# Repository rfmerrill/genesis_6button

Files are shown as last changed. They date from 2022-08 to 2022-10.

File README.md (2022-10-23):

# genesis_6button
Simple PCB + ATTiny404 code for a 6-button mega drive controller.

This is a KiCad project for a board and accompanying ATTiny404 code to implement a replacement for the custom chip in the 6-button mega drive/genesis controller.

**Note: the `main` HEAD is not necessarily tested! Tested revisions of the board+firmware will be tagged**

Latest tested fab here: https://oshpark.com/shared_projects/aK2wBkfg

Currently there is a 14-pin dual row header used for the buttons because I was unaware of the brook 20 pin header at the time. I might add that pinout to future boards.

```
     C  1 | 2  Z
     B  3 | 4  Y
     A  5 | 6  X
  LEFT  7 | 8 GND
 RIGHT  9 | 10 GND
  DOWN 11 | 12 MODE
    UP 13 | 14 START
```

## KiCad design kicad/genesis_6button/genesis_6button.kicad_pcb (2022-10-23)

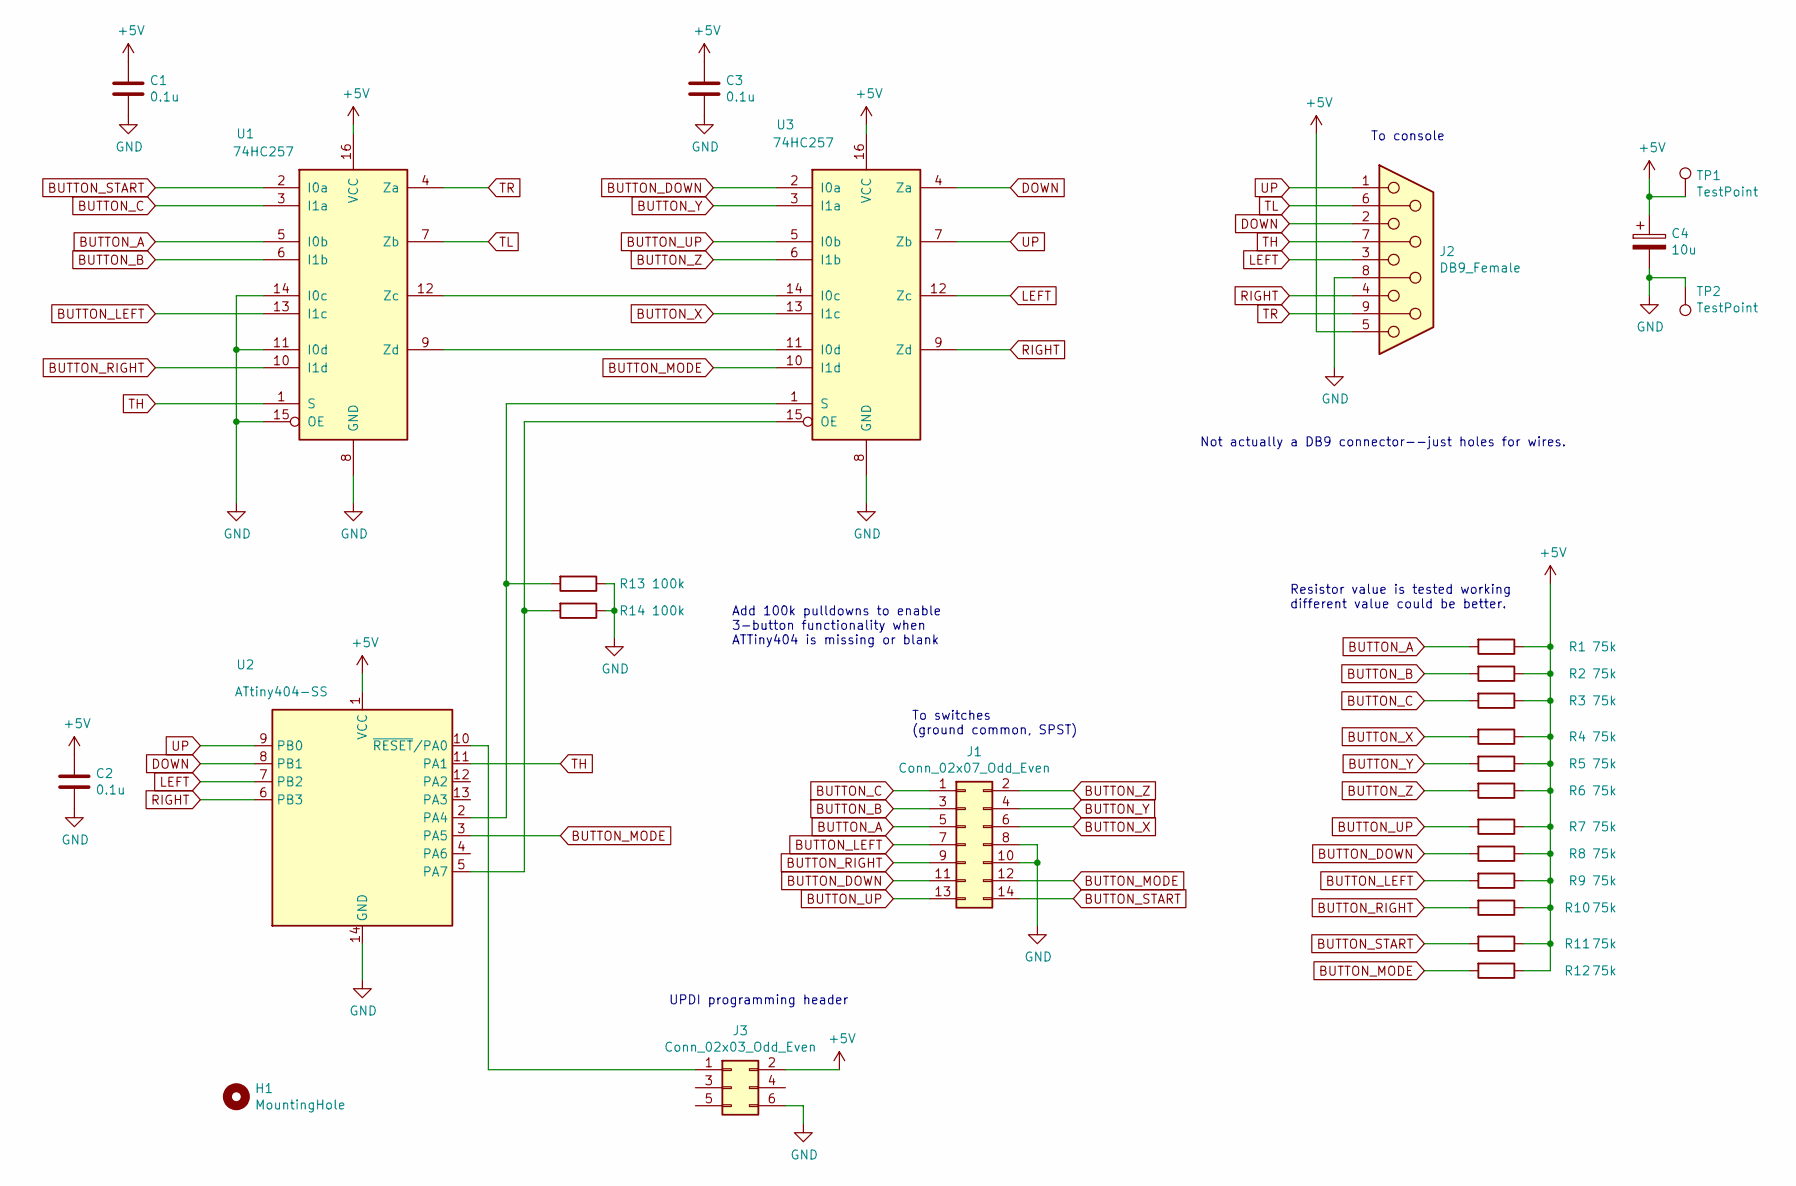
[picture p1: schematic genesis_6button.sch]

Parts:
C1, C2, C3: 0.1u; C_1206_3216Metric
C4: 10u; CP_Radial_D8.0mm_P5.00mm
H1: MountingHole; MountingHole_5.3mm_M5
J1: Conn_02x07_Odd_Even; IDC-Header_2x07_P2.54mm_Vertical
J2: DB9_Female; PinHeader_1x09_P2.54mm_Vertical
J3: Conn_02x03_Odd_Even; IDC-Header_2x03_P2.54mm_Vertical
R1, R2, R3, R4, R5, R6, R7, R8, R9, R10, R11, R12: 75k; R_0805_2012Metric
R13, R14: 100k; R_0805_2012Metric
TP1, TP2: TestPoint; TestPoint_Loop_D3.50mm_Drill0.9mm_Beaded
U1, U3: 74HC257; SOIC-16_3.9x9.9mm_P1.27mm
U2: ATtiny404-SS; SOIC-14_3.9x8.7mm_P1.27mm

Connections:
+5V: C1.1, C2.1, C3.1, C4.1, J2.5, J3.2, R1.1, R2.1, R3.1, R4.1, R5.1, R6.1, R7.1, R8.1, R9.1, R10.1, R11.1, R12.1, TP1.1, U1.16 (VCC), U2.1 (VCC), U3.16 (VCC)
BUTTON_A: J1.5, R1.2, U1.5 (I0b)
BUTTON_B: J1.3, R2.2, U1.6 (I1b)
BUTTON_C: J1.1, R3.2, U1.3 (I1a)
BUTTON_DOWN: J1.11, R8.2, U3.2 (I0a)
BUTTON_LEFT: J1.7, R9.2, U1.13 (I1c)
BUTTON_MODE: J1.12, R12.2, U2.3 (PA5), U3.10 (I1d)
BUTTON_RIGHT: J1.9, R10.2, U1.10 (I1d)
BUTTON_START: J1.14, R11.2, U1.2 (I0a)
BUTTON_UP: J1.13, R7.2, U3.5 (I0b)
BUTTON_X: J1.6, R4.2, U3.13 (I1c)
BUTTON_Y: J1.4, R5.2, U3.3 (I1a)
BUTTON_Z: J1.2, R6.2, U3.6 (I1b)
DOWN: J2.2, U2.8 (PB1), U3.4 (Za)
GND: C1.2, C2.2, C3.2, C4.2, J1.8, J1.10, J2.8, J3.6, R13.1, R14.1, TP2.1, U1.8 (GND), U1.11 (I0d), U1.14 (I0c), U1.15 (OE), U2.14 (GND), U3.8 (GND)
LEFT: J2.3, U2.7 (PB2), U3.12 (Zc)
unnamed: J3.1, U2.10 (~RESET~/PA0)
unnamed: R13.2, U2.2 (PA4), U3.1 (S)
unnamed: R14.2, U2.5 (PA7), U3.15 (OE)
unnamed: U1.9 (Zd), U3.11 (I0d)
unnamed: U1.12 (Zc), U3.14 (I0c)
RIGHT: J2.4, U2.6 (PB3), U3.9 (Zd)
TH: J2.7, U1.1 (S), U2.11 (PA1)
TL: J2.6, U1.7 (Zb)
TR: J2.9, U1.4 (Za)
UP: J2.1, U2.9 (PB0), U3.7 (Zb)

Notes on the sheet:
Not actually a DB9 connector--just holes for wires.
UPDI programming header
Resistor value is tested working different value could be better.
Add 100k pulldowns to enable 3-button functionality when ATTiny404 is missing or blank
To console
To switches (ground common, SPST)

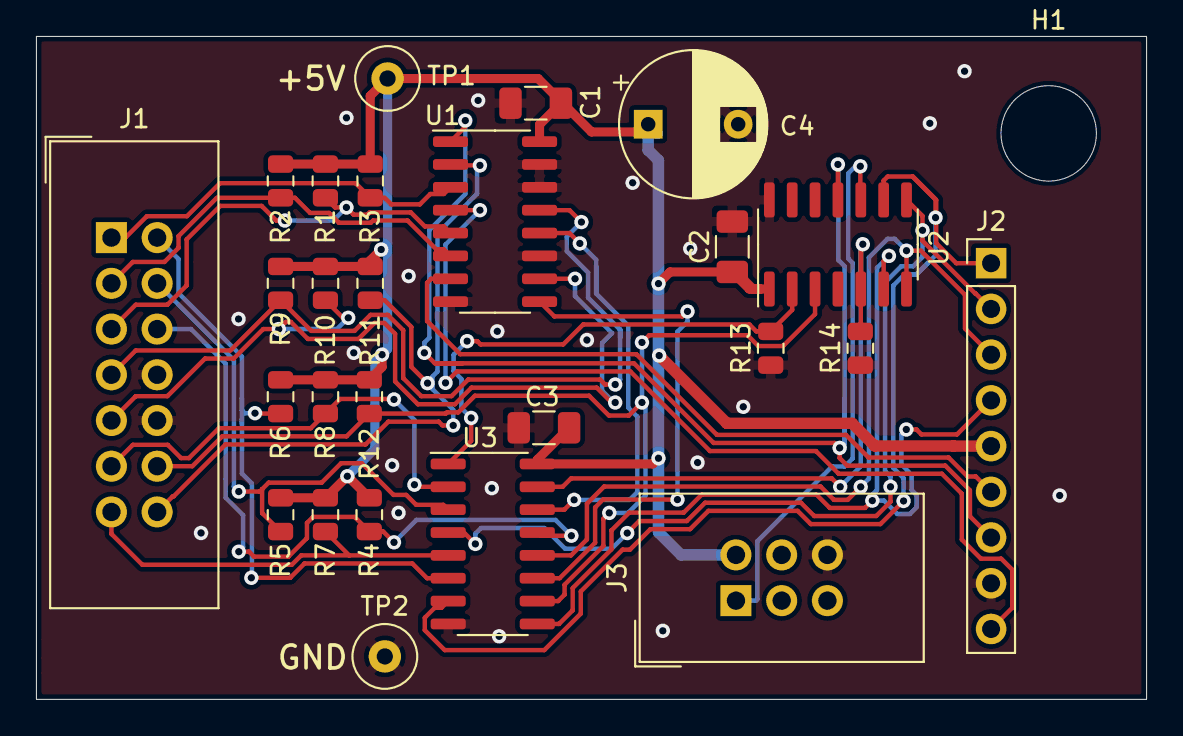
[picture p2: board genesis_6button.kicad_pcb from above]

Board: 2 copper layers, 61.7 x 36.8 mm, 27 parts (0 on the bottom side), 26 nets.

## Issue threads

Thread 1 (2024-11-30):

Hex file of Attiny404

hualazimo7, 2024-11-30:
Can you provide the firmware of attiny404?

rfmerrill, 2024-12-03:
It's been so long since I touched this project that I no longer am sure which revision I should build to give you a hex file, plus I have a new computer and don't have the compiler installed anymore. I might be able to get it for you in a while but I would want to be able to re-test it before I tell anyone to use it, which would mean finding one of the boards, hooking it up etc etc.

It shouldn't be too hard for you to build yourself--it's a really simple project, and Atmel Studio/Microchip Studio is free and not too hard to install.

Closed 2024-12-09.

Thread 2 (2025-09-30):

BOM, cable wiring, improved silkscreen

danboid, 2025-09-30:
I'm interested in building one of these boards but it needs a bit more documentation.

Could you please add a BOM to the repo? It seems there is a mostly complete BOM here:

https://oshpark.com/shared_projects/aK2wBkfg

but it is missing designators for the parts - its mainly U1, U2 and U3 and J3 that I'm unsure of.

I would also need a pinout diagram showing how to wire J2 up to a cable.

It would be good to see the silkscreen improved to show the button wiring on the PCB.

Thanks

rfmerrill, 2025-09-30:
All of the information you need is in the KiCAD project, but I didn't include a schematic print in the repo which is actually a pet peeve of mine when other people do it. Unfortunately it's been so long that I don't think I even have KiCAD installed anymore.

> but it is missing designators for the parts - its mainly U1, U2 and U3 and J3 that I'm unsure of.

It should be obvious which footprint is the microcontroller and which are the two multiplexers because they have different pin counts. I believe U2 is the microcontroller.

J3 is a standard 2x3 IDC header, which I _think_ will mate with either the USBtinyISP or the Atmel ICE's AVR adapter pigtail. If you just search for "2x3 IDC socket" pretty much any of them will work as long as you get one with the common 0.1" pin pitch.

> I would also need a pinout diagram showing how to wire J2 up to a cable.

Ah I feel bad that I didn't include this because I don't even remember! I want to believe that I was a good boy and used the same pin numbering as the joystick connector itself, but I cannot guarantee that I did, unfortunately.

> It would be good to see the silkscreen improved to show the button wiring on the PCB and adding a photo of a populated, wired board to the README.

Agree, and these seem like easy tasks for someone to do :)

rfmerrill, 2025-09-30:
OK, I have been able to confirm that I _was_ in fact a good boy and J2's pin numbering matches the joystick plug. Note: that pinout diagram you posted reflects the _socket_--the plug is mirrored from that. Also those pinout descriptions are for the actual atari consoles, but we only care about the pin numbers in this case.

Here is a photo of one of the boards I assembled that I was able to dig up:

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

Please **ignore the wire colors** as while Sega may have been consistent, third parties definitely were not.

There are a handful of minor mods here--points to clip to for supply voltage, an extra capacitor (don't remember why, probably not needed) and a jumper wire that allows for supporting 3-button mode (hold down MODE on powerup).

You'll also notice I just used 2-row pin headers instead of IDC. This is also fine it just means you lose the keying and have to pay attention to pin 1.

> Would you recommend that we use the gerbers from the latest commit or the tested version?

Ah, there are not actually any gerbers here... I don't remember what changed from the tested version to the latest commit. Tested version is probably safer I assume.

rfmerrill, 2025-09-30:
And no, that's not hot glue, it's RapidFix UV resin. I don't own a hot glue gun.

danboid, 2025-09-30:
Final question today / tonight is have you ever heard of the open source 8 bit Uzebox games console before I started bombarding you? Its the fastest, cheapest, most open and easiest to build 8 bit console platform, if any of that appeals to you?

https://uzebox.org/

rfmerrill, 2025-10-01:
maybe someday, my time is mostly taken up with work and guitar practice these days. I'm sure I'll get back into gaming sometime!

danboid, 2025-10-02:
Guitar practice is definitely a better use of your time than playing games IMO. I find trying to write games more fun than playing them.

I support the Uzebox because I think we need a fully  open retro platform and its a great project for people learning electronics to get started with. Same goes for the Spectrum Next. They compliment each other well.

danboid, 2025-10-02:
I'm hoping to make a start on building this soon. I've still not even tried building the code yet.

rfmerrill, 2025-10-03:
I don't know if the `main` version of the kicad project even passes DRC or works at all, tbh, but godspeed if you want to try it out.

If you're going to credit me, give my github URL I guess?

danboid, 2025-10-03:
I have got the attiny code to build under Linux using `avr-gcc`. I'm pretty sure you need at least `avr-gcc` v8 or later to build for the attiny404.

I used these commands which we can put into a build script when I update (my fork of) the repo:

```
avr-gcc -mmcu=attiny404 -Os -Wall -Wextra main.c -o main.elf
avr-objcopy -O ihex -R .eeprom main.elf main.hex
```

rfmerrill, 2025-10-03:
@danboid thanks so much! The one thing I'm wondering about is if there were fuse settings you might need in addition to the code. I think I would have put them in the comments if so? I don't think the 404 is one where you have to mess with fuses as much. My memory is so bad though

rfmerrill, 2025-10-03:
> I found it interesting that the latest rev has one mount hole in the top right corner.

Yeah I just wanted a hole I could slip a cable tie into so that the joystick cable isn't hanging by its solder joints. I'm not a mechanical engineer as you can tell.

danboid, 2025-10-04:
According to KiCAD v9's DRC, there was one thermal relief error with the last v1 revision of the PCB. I seem to have fixed that by slightly moving U3. I have most of the information I suggested get added to the silkscreen and I've added 4x M2 mount holes.

I think I'm just about done now apart from maybe rounding the edges of the board off. Could you check I've got the button labels correct please?

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

https://github.com/danboid/genesis_6button

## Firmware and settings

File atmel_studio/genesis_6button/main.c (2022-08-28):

/*
 * genesis_6button.c
 *
 * Created: 8/24/2022 6:51:32 PM
 * Author : rfm
 */

#include <avr/interrupt.h>
#include <avr/io.h>
#include <stdbool.h>

#define F_CPU_HZ 10000000
#define F_PER_HZ 10000000

#define TIMEOUT_SEC 0.002  // 2 ms
#define TIMEOUT_PER_CLKS (F_PER_HZ * TIMEOUT_SEC)

static volatile bool timeout = false;

static inline void pins_3button(void)
{
    cli();
    PORTB_DIR = 0;          // PBx all set to input
    VPORTA_OUT &= ~_BV(4);  // Select 0
    VPORTA_OUT &= ~_BV(7);  // Output enable
    PORTB_OUT = 0x00;       // PB0-3 low pre-load
    sei();
}

static inline void pins_low(void)
{
    cli();
    VPORTA_OUT |= _BV(7);  // Output disable
    PORTB_DIR = 0x0F;      // PB0-3 output
    VPORTA_OUT |= _BV(4);  // Select 1 (pre-load)
    sei();
}

static inline void pins_xyz(void)
{
    cli();
    PORTB_DIR = 0;          // PBx all set to input
    VPORTA_OUT &= ~_BV(7);  // Output enable
    PORTB_OUT = 0x0F;       // PB0-3 drive high pre-load
    sei();
}

static inline void pins_high(void)
{
    cli();
    VPORTA_OUT |= _BV(7);   // Output disable
    PORTB_DIR = 0x0F;       // PB0-3 output
    VPORTA_OUT &= ~_BV(4);  // Select 0 (pre-load)
    sei();
}

ISR(TCA0_CMP0_vect)
{
    TCA0_SINGLE_INTFLAGS = TCA_SINGLE_CMP0_bm;
    TCA0_SINGLE_CTRLA = 0;  // Disable, no divider
    timeout = true;
    PORTB_DIR = 0;          // PBx all set to input
    VPORTA_OUT &= ~_BV(4);  // Select 0
    VPORTA_OUT &= ~_BV(7);  // Output enable
}

static inline void start_timer(void)
{
    timeout = false;
    TCA0_SINGLE_CTRLA = 0;                     // Disable, no divider
    TCA0_SINGLE_CNT = 0;                       // zero count
    TCA0_SINGLE_CTRLB = TCA_SINGLE_CMP0EN_bm;  // CMP0 enable
    TCA0_SINGLE_CMP0 = TIMEOUT_PER_CLKS;
    TCA0_SINGLE_INTCTRL = TCA_SINGLE_CMP0_bm;
    TCA0_SINGLE_CTRLA = TCA_SINGLE_ENABLE_bm;  // Enable!
}

static inline bool th_high(void)
{
    return (0 != (VPORTA_IN & _BV(1)));
}

static inline bool th_low(void)
{
    return (0 == (VPORTA_IN & _BV(1)));
}

// Wait 0.6 microsecond
static inline void th_wait(void)
{
    asm("nop");
    asm("nop");
    asm("nop");
    asm("nop");
    asm("nop");
    asm("nop");
}

static inline void th_wait_for_high(void)
{
    th_wait();
    while (th_low())
    {
        // wait
    }
}

static inline void th_wait_for_low(void)
{
    th_wait();
    while (th_high())
    {
        // wait
    }
}

int main(void)
{
    CCP = 0xD8;
    CLKCTRL_MCLKCTRLB = 0x0001;  // Prescaler enabled with 1/2.

    PORTA_DIR = _BV(4) | _BV(7);         // PA4 and PA7 as outputs.
    PORTA_PIN5CTRL |= PORT_PULLUPEN_bm;  // Pin 5 pulled up.

    pins_3button();

    // Wait to make sure we give time for MODE to rise
    th_wait();
    th_wait();
    th_wait();
    th_wait();

    if (0 == (PORTA_IN & _BV(5)))
    {
        // MODE button held, stay in 3-button forever
        while (true)
        {
            // loop forever
        }
    }

    while (true)
    {
        pins_3button();

        th_wait_for_low();

        // still in 3-button mode. We start timer on a rising edge

        th_wait_for_high();

        // First rising edge, start timer.
        start_timer();

        // Wait for 2 more cycles, check for timeout.
        th_wait_for_low();
        if (timeout)
        {
            continue;
        }

        th_wait_for_high();
        if (timeout)
        {
            continue;
        }

        th_wait_for_low();
        // Recognition cycle
        pins_low();
        // Check for timeout *after* changing pins.
        // that way we don't end up stuck waiting with
        // pins in the wrong configuration.

        if (timeout)
        {
            continue;
        }

        th_wait_for_high();
        // XYZ cycle
        pins_xyz();
        if (timeout)
        {
            continue;
        }

        th_wait_for_low();
        // Technically undefined here, but some software
        // expects us to output high.
        pins_high();

        while (!timeout)
        {
            // Wait for timeout to start the cycle again.
        }
    }
}

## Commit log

2022-08-25 Add atmel studio proj + kicad proj.
    [genesis_6button.kicad_pcb, genesis_6button.sch]
2022-08-25 Change to actual component values + comments
    [genesis_6button.kicad_pcb, genesis_6button.sch]
2022-08-27 Fix erroneous waiting for TH transition
    [main.c]
2022-08-28 Use MODE on pin 3 to select 3-button mode
2022-08-28 Second PCB iteration (untested)
    [genesis_6button.kicad_pcb, genesis_6button.sch]
2022-08-30 Add hole for cable tie + replace/route
    [genesis_6button.kicad_pcb, genesis_6button.sch]
2022-08-31 Shrink board.
    [genesis_6button.kicad_pcb]
2022-10-23 Re-annotate and update pcb
    [genesis_6button.kicad_pcb, genesis_6button.sch]
